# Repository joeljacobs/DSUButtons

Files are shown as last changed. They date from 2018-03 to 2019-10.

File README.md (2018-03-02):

# Reenable DSU Buttons and Remotely Disable DSU on Rav4
I noticed the following distance and Lane Keeping Alert buttons no longer did anything after installing Open Pilot and disabling the DSU. I wanted them back. So through some help from the internet and Comma Slack folks, I figured out what was needed.

## Hardware List (see bottom for links)
* Arduino (I used a Duo)
* CAN bus SPI board
* Connectors and Wires
* Relay board if trying to disable/enable DSU

## Location
Just about everything is done behind the glove compartment. Squeeze in the sides of the glove compartment until it comes loose, then disconnect the arm holding it in by pulling it to the left. Then just lift it out.

The DSU is the left-most large connector you can see in the middle of where the glove compartment was removed.

Here's the connector. I've highlighted the pins for the buttons:
* 28 GND
* 23 Distance Control
*  5 Lane Keeping Assist Switch
* 10 Can2 High
* 11 Can2 Low
*  7 12V

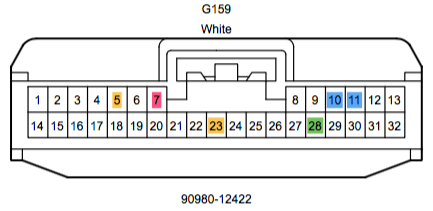
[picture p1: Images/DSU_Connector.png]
DSU Connector


The buttons simply Conect to Ground when you press them. So this seemed like a good use for an Arduino.

But I also wanted my EON to be able to communicate with it, so CAN was the natural solution.
I already had a few CAN boards that use the SPI protocol to communicate with Raspberry Pi's and Arduinos, so I used one of those.

It was then just a matter of connecting the pins to the arduino's digital IO, connecting the CAN board to the Arduino, and connecting the CAN board to the CAN bus in the same DSU connector. 

## Automatically Disconnect/Reconnect DSU
I have two cars that can use Open Pilot, and I have to move it between them sometimes. When I do, I need to re-enable the DSU (as well as changes some stuff on the EON) each time. I added some relays to allow that to be more automatic in this circuit as well. 

## Code
I've included some amateur code for the Arduino that reads the buttons, writes CAN and controls the relays. 

For the CAN Bus SPI board I bought, you have to use a custom library on the Arduino, since the normal code doesn't support the slower clock speed (8mhz.) Here it is:
https://github.com/Flori1989/MCP2515_lib

### Hardware Links
#### CAN Module I used:
https://www.amazon.com/gp/product/B015W4D9WY/ref=oh_aui_detailpage_o01_s01?ie=UTF8&psc=1

#### CAN Arduino Shield that I should have probably used instead:
https://www.amazon.com/gp/product/B06XWQ4WF9/ref=oh_aui_detailpage_o05_s00?ie=UTF8&psc=1
#### Relay Board:
https://www.amazon.com/SunFounder-Channel-Optocoupler-Expansion-Raspberry/dp/B00E0NTPP4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

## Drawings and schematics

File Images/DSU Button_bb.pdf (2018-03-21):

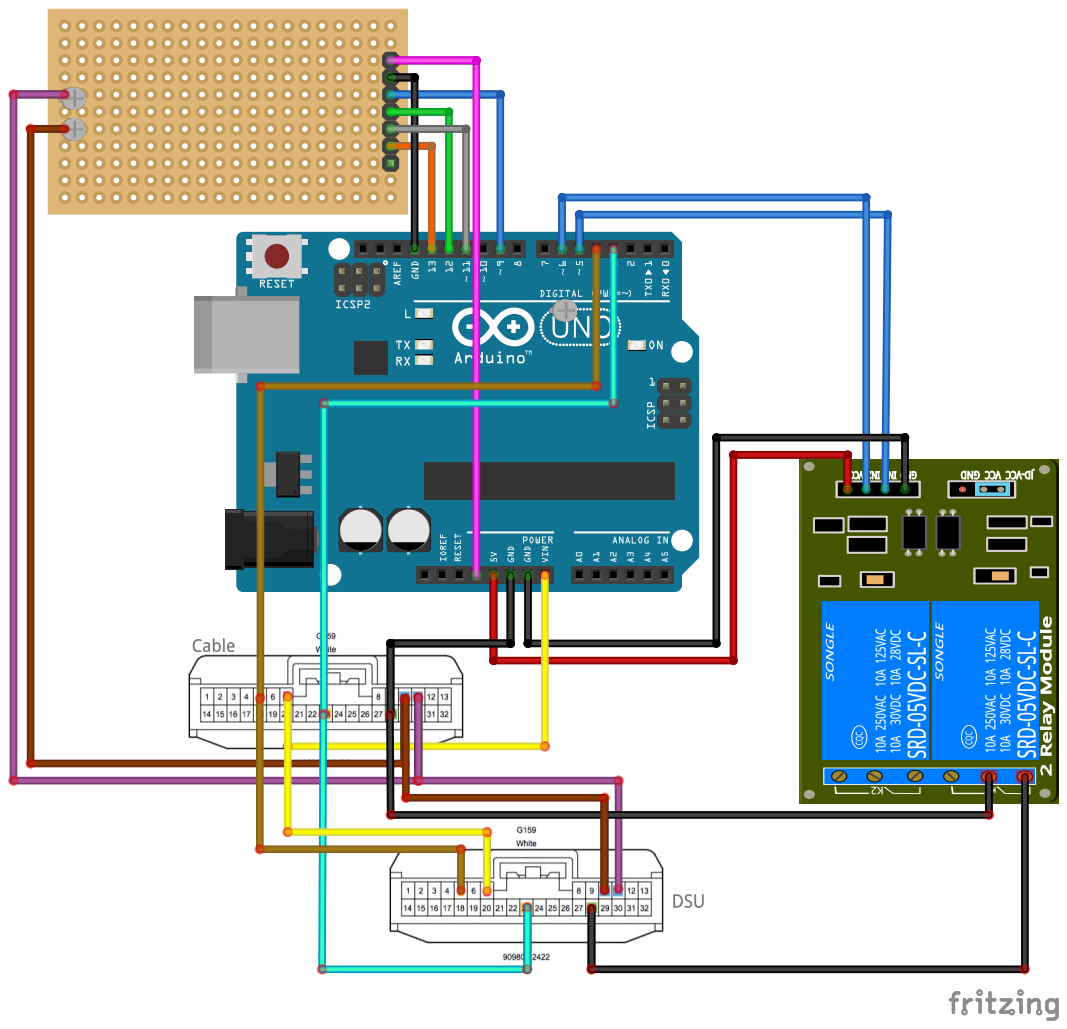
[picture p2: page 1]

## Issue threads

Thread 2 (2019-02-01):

What connectors to use?

zhou13, 2019-02-01:
Hi Joel Jacobs,

Thanks for your posting your interesting project! One question I have is that what connectors did you use when you wired your DSUButtons? Is it possible to do that without cutting/splicing the origin cables in the car?  I guess I could buy an addition 90980-12422 but I do not know the part number for the female connector.

Thank you!

Best,
Yichao Zhou.

arne182, 2019-02-01:
3D printed Part 1612050 https://www.thingiverse.com/thing:3170223 Connector F 90980-12422 https://www.toyotapartsdeal.com/oem/toyota~housing~connector~f~90980-12422.html

zhou13, 2019-02-01:
Awesome. Thanks!

Closed 2019-02-01.

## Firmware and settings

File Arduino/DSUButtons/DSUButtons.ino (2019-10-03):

#include <mcp_can_dfs.h>
#include <mcp_can.h>

#include <SPI.h>


//IO Pins
const int fdistance = 3;
const int lanewarn = 4;
const int relay1 = 5;
const int relay2 = 6;

//CAN
const int SPI_CS_PIN = 9;
unsigned char len = 3;
unsigned char buf[8];
unsigned long interval=100; // the time we need to wait
unsigned long previousMillis=0; // millis() returns an unsigned long.
unsigned char stmp[5] = {0, 0, 0, 0, 0};
unsigned char JOEL_ID[2] = {0, 0};
unsigned char NEW_MSG_1[8] = {0};
long unsigned int rxId;
unsigned char rxBuf[8];
MCP_CAN CAN(SPI_CS_PIN);
int canSendId = 0x203;

//Logic variables
int fdistanceState = 1;
int lanewarnState = 1;
int lane100mscount = 0;
int dist100mscount = 0;
int relaystate = 0; // 0 = DSU off?

////SERIAL INPUT (UNUSED)
//char receivedChar;
 
void setup()
{ 
  //GPIO
  pinMode(fdistance, INPUT);
  pinMode(lanewarn, INPUT_PULLUP);
  pinMode(relay1, OUTPUT);
  pinMode(relay2, OUTPUT);
  digitalWrite(relay1, relaystate); //Remember Relay is Backward - HIGH means off
  digitalWrite(relay2, relaystate);

  //Serial 
  Serial.begin(115200);
  
 //SPI (CAN)
  SPI.begin();  
  SPI.setClockDivider(SPI_CLOCK_DIV2);
  
 //CAN
  if(CAN.begin(MCP_STDEXT, CAN_500KBPS, MCP_8MHZ) == CAN_OK) Serial.print("MCP2515 Init Okay!!\r\n");
  else Serial.print("MCP2515 Init Failed!!\r\n");
  pinMode(2, INPUT);                       // Setting pin 2 for /INT input




  CAN.init_Mask(0,0,0x03FFFFFF);                // Init first mask...
  CAN.init_Mask(1,0,0x03FFFFFF);                // Init second mask... 
  CAN.init_Filt(0,0,0x04140000);                // Init first filter...
//  CAN.init_Filt(1,0,0x02010000);                // Init second filter...

  CAN.setMode(MCP_NORMAL);                // Change to normal mode to allow messages to be transmitted
}

////SERIAL INPUT (unused)
//void recvOneChar() {
//    if (Serial.available() > 0) {
//        receivedChar = Serial.read();
//    }
//}

//MAIN LOOP
void loop()
{

  fdistanceState = digitalRead(fdistance);
  //Serial.println(fdistanceState);
  lanewarnState = digitalRead(lanewarn);  

  //CAN Write SUB-LOOP
  // Only want to send messages every 100 ms
  unsigned long currentMillis = millis(); // grab current time
  //check if "interval" time has passed (100 milliseconds)
  if ((unsigned long)(currentMillis - previousMillis) >= interval) {

    if (fdistanceState == LOW) {
      JOEL_ID[0] = 0b10000000;
      dist100mscount++;
    } else {
      JOEL_ID[0] = 0b00000000;
      dist100mscount = 0;
    }


    if (lanewarnState == LOW) {
      JOEL_ID[1] = 0b10000000;
      lane100mscount++;
    } else {
      JOEL_ID[1] = 0b00000000;
      lane100mscount = 0;
    }
    CAN.sendMsgBuf(canSendId, 0, 2, JOEL_ID);
    //Serial.println(dist100mscount);
    if ((fdistanceState == LOW) && (dist100mscount == 10)) {
      dist100mscount = 0;
      if (relaystate == 0){
        relaystate = 1;
        Serial.println("relay=1");
        digitalWrite(relay1, relaystate);
        digitalWrite(relay2, relaystate);
      }
      else if (relaystate == 1) {
        relaystate = 0;
        Serial.println("relay=0");
        digitalWrite(relay1, relaystate);
        digitalWrite(relay2, relaystate);
      }
    }
    previousMillis = millis();
  }

  if(!digitalRead(2))                   // check if CAN receive is enabled
      {
      CAN.readMsgBuf(&rxId, &len, rxBuf); // Read data: len = data length, buf = data byte(s)
//        Serial.print("ID: ");
//        Serial.print(rxId, HEX);
//        Serial.print(" Data: ");
//        for(int i = 0; i<len; i++)           // Print each byte of the data
//        {
//          if(rxBuf[i] < 0x10)                // If data byte is less than 0x10, add a leading zero
//          {
//            Serial.print("0");
//          }
//          Serial.print(rxBuf[i], HEX);
//          Serial.print(" ");
//        }
//        Serial.println();
        if(rxBuf[6] == 0x16) {
          Serial.println("EON NOT ON - Stock!");
        }
      }

 // pseudo code:
 // Start with DSU off.
 // if we don't see an EON packet in x seconds, turn DSU on. (x is the maximum the DSU can stay off before a force-restart error occurs)
 // Make the change permanent until next restart of car. Can stop looking for ID at that point.
 // future: send a can packet to switch the DIPs as well
 // and EON packet is defined as an id and data that only the EON puts out. So it can be both an ID and data -since most, if not all
 // id's are common with the EON and the DSU. So we'd look at some of the "values.py" values that the EON always sends as an example packet.
}

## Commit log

2018-03-02 Added Relay info
2018-03-02 Added Toyota wiring diagrams
2018-03-21 Added wiring diagram
    [DSU Button.fzz]
2018-10-09 Switched to better can library, and started building DSU switching logic.
